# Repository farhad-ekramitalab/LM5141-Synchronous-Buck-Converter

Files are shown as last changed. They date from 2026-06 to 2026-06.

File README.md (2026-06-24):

# LM5141-Q1 Synchronous Buck Converter

## Project Overview

Design and implementation of a 12 V to 3.3 V, 5 A synchronous buck converter using the Texas Instruments LM5141-Q1 peak-current-mode controller.

This project covers the complete development flow:

- Power-stage design
- LTspice simulation
- Control-loop design
- Compensation design
- KiCad schematic capture
- 4-layer PCB layout
- Manufacturing preparation
- Hardware validation (in progress)
Schematic KiCad
Layout KiCad
3D Render KiCad

---
## 📄 Portfolio Report

A concise engineering portfolio summarizing the complete design workflow, including system specifications, LTspice simulations, control-loop design, PCB implementation, manufacturing, and engineering skills demonstrated throughout the project.

**Report:**

[`Docs/LM5141-Synchronous Buck Converter Report.pdf`](Docs/LM5141-Synchronous%20Buck%20Converter%20Report.pdf)

## Specifications

| Parameter | Value |
|---|---|
| Input Voltage | 8 V – 16 V |
| Nominal Input Voltage | 12 V |
| Output Voltage | 3.3 V |
| Output Current | 5 A |
| Switching Frequency | 440 kHz |
| Topology | Synchronous Buck |
| Controller | LM5141-Q1 |
| Control Method | Peak Current Mode |

---

## Design Highlights

- Peak current mode control
- Type-II compensation network
- Loop crossover frequency ≈ 37 kHz
- Phase margin ≈ 83°
- 4-layer PCB implementation
- Kelvin current sensing
- AGND / PGND separation
- Optimized switching-node layout

---

## Current Status

- [x] Power stage design completed
- [x] LTspice simulation completed
- [x] Compensation design completed
- [x] KiCad schematic completed
- [x] PCB layout completed
- [x] PCB ordered
- [ ] Assembly
- [ ] Hardware validation
- [ ] Efficiency characterization
- [ ] Thermal characterization
---

## Tools Used

- LTspice
- KiCad 9
- TI WEBENCH
- Oscilloscope (planned validation)

---

## 🔗 Additional Resources

* 📁 **KiCad Project:** `KiCad/`
* ⚡ **LTspice Simulations:** `LTspice/`
* 🖼️ **Project Images:** `Images/`
* 📦 **Bill of Materials (BOM):** `BOM/`
* 📄 **Portfolio Report:** `Docs/LM5141-Synchronous Buck Converter Report.pdf`

---

## Author

Farhad Ekramitalab

Hardware Engineer | Power Electronics | SMPS | PCB Design | LTspice

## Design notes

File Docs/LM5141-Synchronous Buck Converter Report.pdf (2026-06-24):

LM5141-Q1 Automotive Synchronous Buck Converter

### 12 V → 3.3 V, 5 A | Peak Current Mode Control

Farhad Ekramitalab
Hardware Engineer | Power Electronics | PCB Design | LTspice | KiCad

PROJECT OVERVIEW

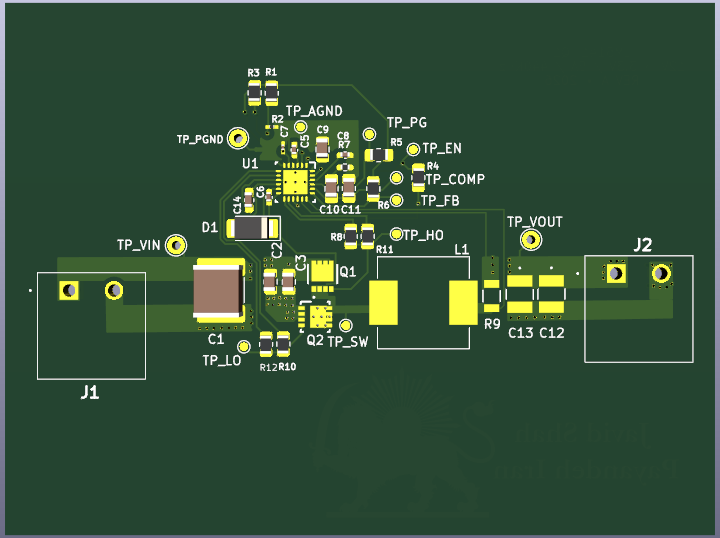
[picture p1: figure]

Project Summary
This project presents the complete design and implementation of a 12 V to 3.3 V, 5 A synchronous buck converter using the Texas Instruments LM5141-Q1 automotive-qualified controller.
The project was developed following a complete engineering workflow including system specification, power-stage design, control-loop design, LTspice simulation, schematic capture, PCB layout, and manufacturing preparation.
The design was implemented using LTspice, TI WEBENCH, and KiCad and has been released for PCB fabrication through JLCPCB.

Key Specifications

Parameter | Value
Input Voltage | 8 V – 16 V
Nominal Input | 12 V
Output Voltage | 3.3 V
Output Current | 5 A

Switching Frequency 440 kHz

Topology | Synchronous Buck
Controller | LM5141-Q1
Control Method | Peak Current Mode
PCB Stackup | 4 Layers

Industry Relevance
The converter was developed following automotive and industrial power electronics design practices.
Particular attention was given to EMC-aware PCB layout techniques including:
- Hot-loop minimization
- Compact switching-node geometry
- Kelvin current sensing
- AGND / PGND separation
- Optimized gate-drive routing
These design practices are commonly used in professional automotive power conversion systems and support future EMC/EMI compliance activities.

CONTROL LOOP DESIGN & SIMULATION

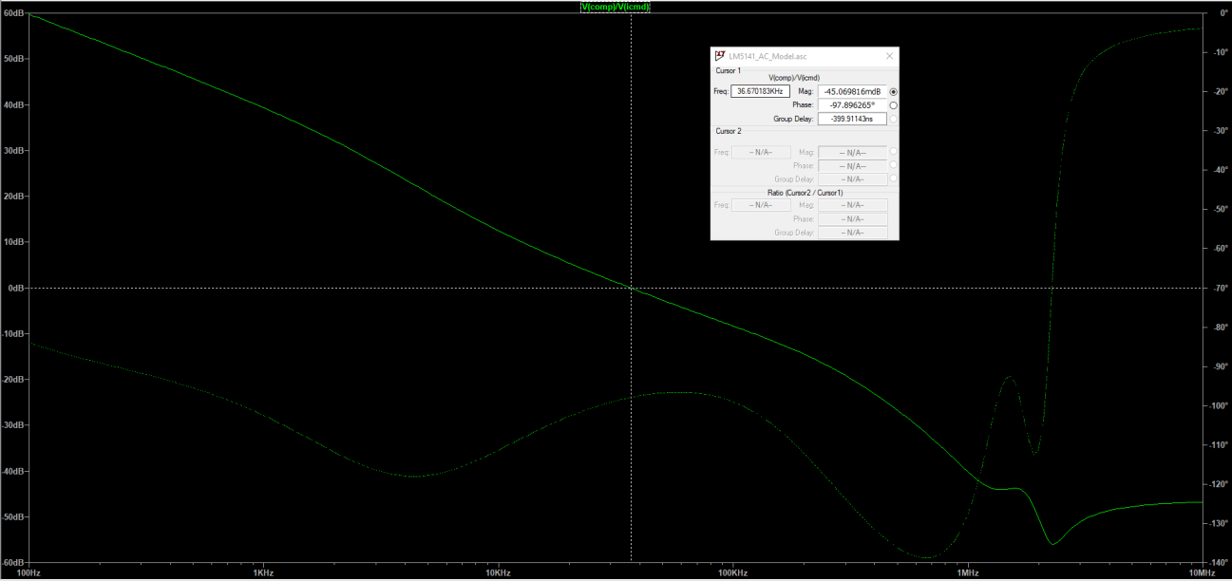
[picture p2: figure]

Stability Results
- Control Method: Peak Current Mode
- Compensation: Type-II
- Crossover Frequency: ~37 kHz
- Phase Margin: ~83°
- Switching Frequency: 440 kHz
The compensation network was designed and validated using LTspice averaged AC analysis. The resulting loop response provides robust stability and excellent transient performance while maintaining sufficient bandwidth for fast load regulation. Simulation Activities
- Startup analysis
- Load transient analysis
- Line transient analysis
- Loop-gain verification
- Compensation optimization

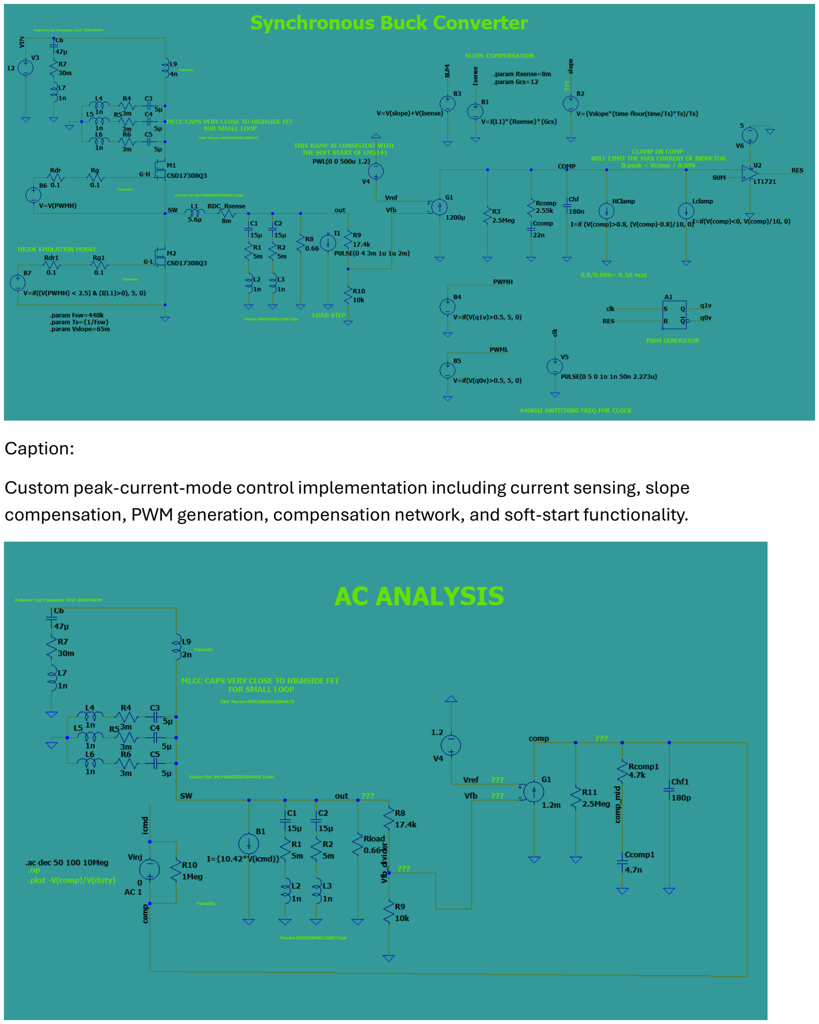
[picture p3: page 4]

Caption:
Custom peak-current-mode control implementation including current sensing, slope compensation, PWM generation, compensation network, and soft-start functionality.

SCHEMATIC & PCB IMPLEMENTATION Schematic Capture

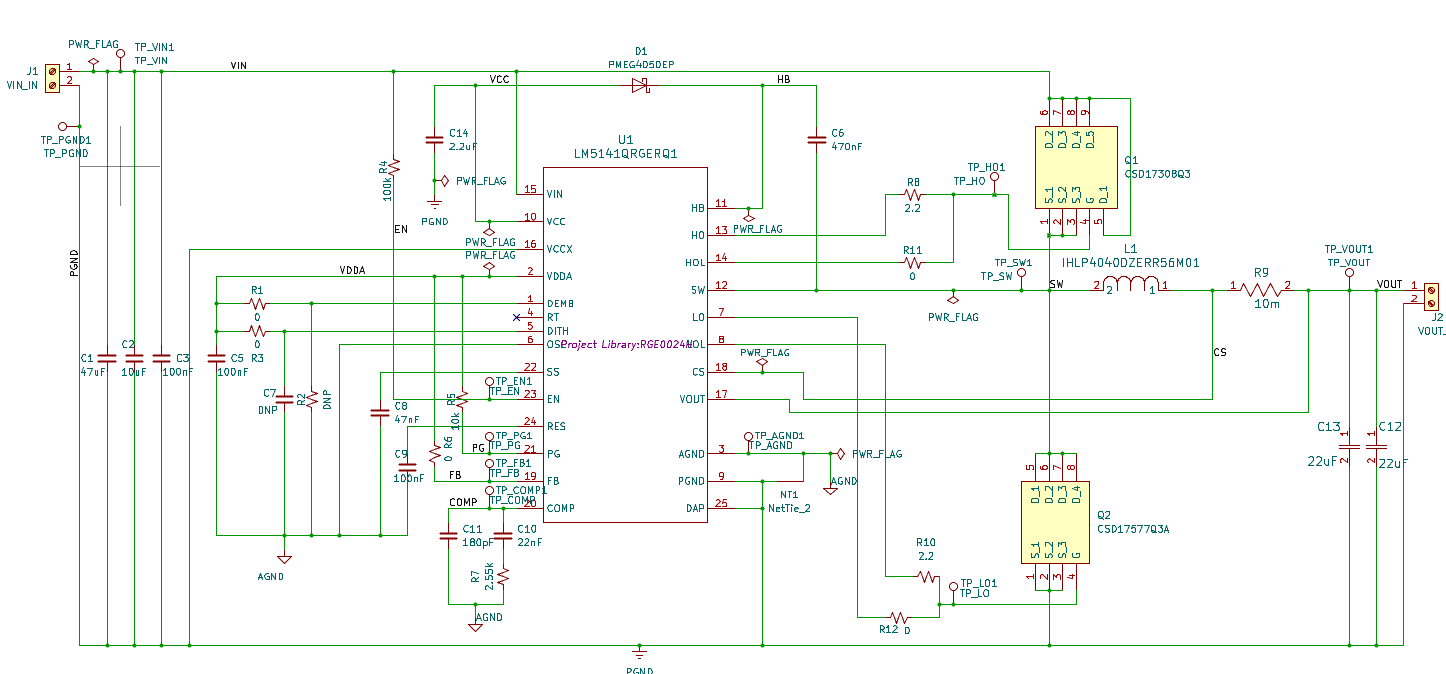
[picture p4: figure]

The complete converter was implemented in KiCad and includes:
- LM5141-Q1 controller
- Bootstrap circuitry
- Synchronous MOSFET stage
- Current sensing network
- Compensation network
- Input and output filtering

PCB Layout

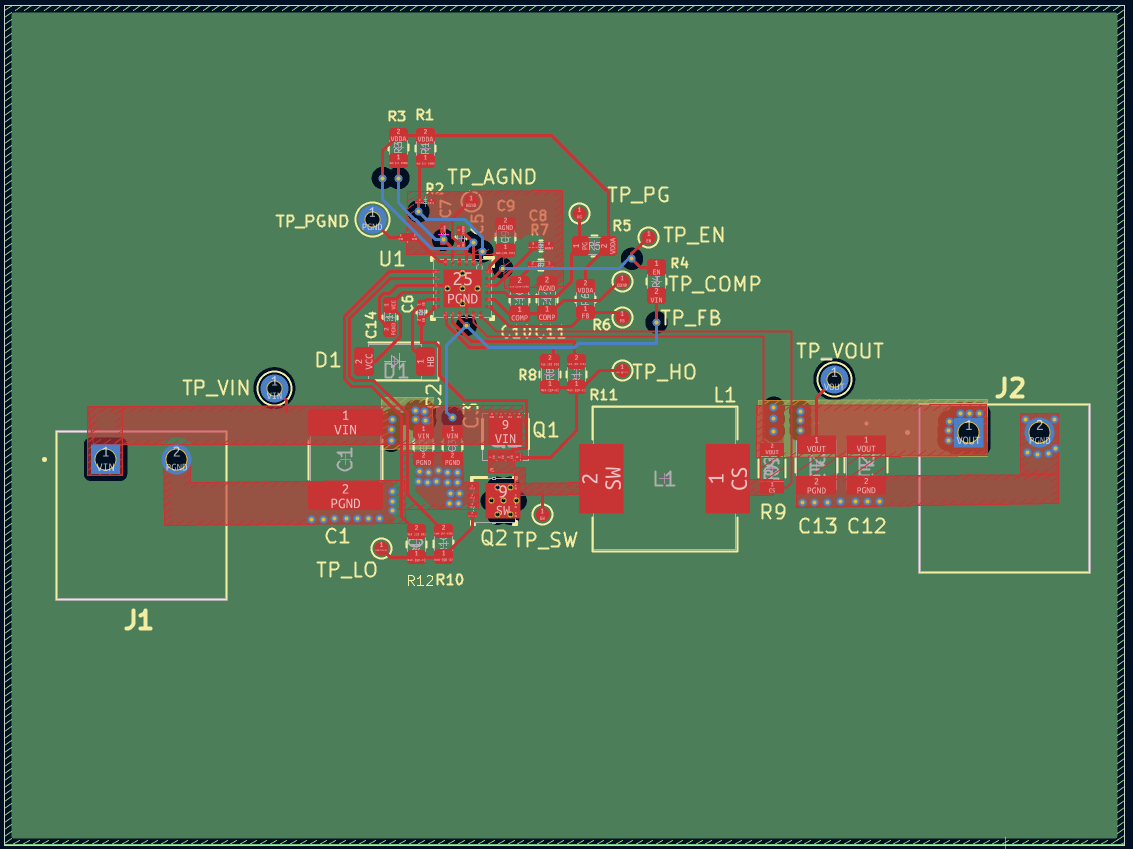
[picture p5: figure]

The PCB was implemented as a four-layer design using industry-standard switching power supply layout techniques.
Layout Highlights
- Hot-loop minimization
- Compact power-stage placement
- Kelvin current sensing
- AGND / PGND separation using net tie
- Short gate-drive loops
- Test-point strategy for validation
- Manufacturing-ready layout

Engineering Skills Demonstrated:

Power Electronics Design - DC-DC Converter Design - Peak Current Mode Control -Compensation Design - Loop Stability Analysis - LTspice Simulation - PCB Design (KiCad) -EMC-Aware Layout Techniques - Design for Manufacturing (DFM) - Technical Documentation

Engineering Tools:
✓ LTspice
✓ KiCad
✓ TI WEBENCH
✓ JLCPCB
✓ Datasheet Analysis
✓ PCB Design
Repository
GitHub Repository:
https://github.com/farhad-ekramitalab/LM5141-Synchronous-Buck-Converter
Future Validation Plan
The next phase of the project includes hardware assembly and laboratory characterization. Planned validation activities include:
- Startup verification
- Output ripple measurement
- Load transient testing
- Efficiency characterization
- Thermal analysis
- EMI/EMC-oriented waveform evaluation
This project demonstrates the complete workflow of a modern power electronics design from specification through simulation, PCB implementation, and manufacturing release.

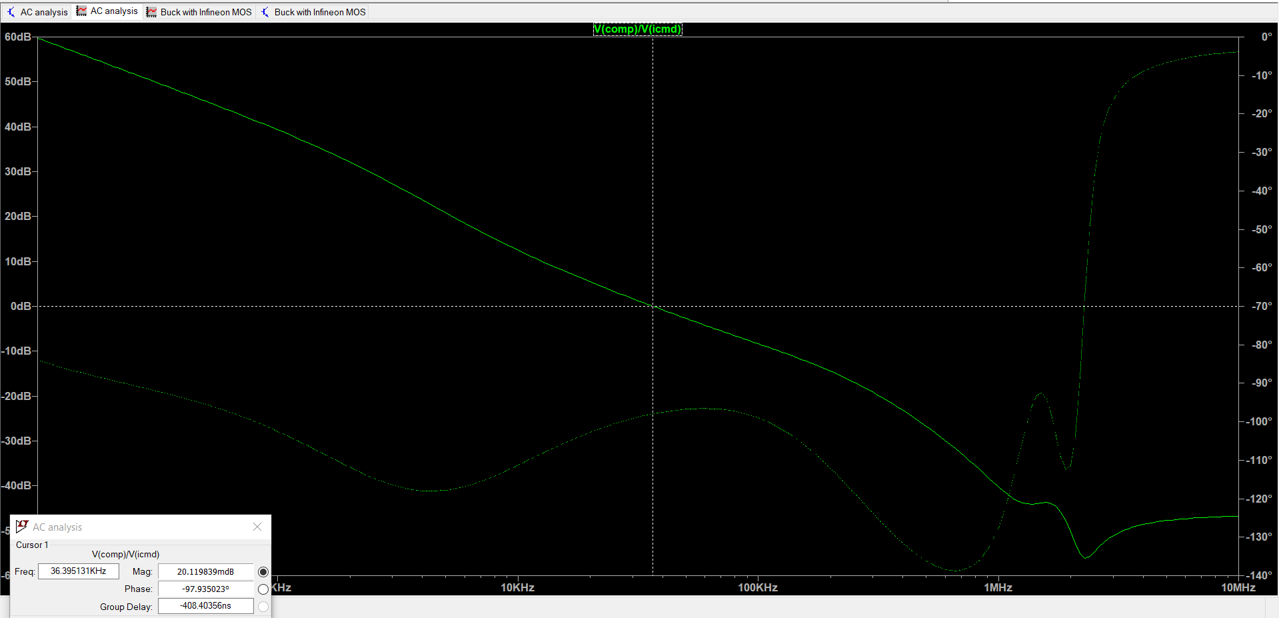
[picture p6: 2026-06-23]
Images/Bode Plot.PNG

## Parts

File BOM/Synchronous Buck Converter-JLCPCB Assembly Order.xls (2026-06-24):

JLCPCB BOM Tool - BOM Matching
BOM name：Synchronous Buck Converter-JLCPCB Assembly Order.xlsx |  |  | Download Time：2026-06-23 06:31:29 |  |  |  | * Our matching results are updated in real-time, but stock and prices may change. If it's been over 24 hours, please re-match before placing your order.
PCB Assembled Qty：5 |  |  | Est. Total Price：35.0266
Your BOM |  |  |  |  | Matched Parts |  |  |  |  |  |  | Order Information
Top Designator | Bottom Designator | Comment | Footprint | JLCPCB Part # | Matches | Part # | Manufacturer | Footprint | Description | Category | Warning | JLCPCB Part # | Product link | Lib Type | Qty | Source | Total Price ($)
C1 |  | 47uF | Capacitor_SMD:C_2220_5750Metric_Pad1.97x5.40mm_HandSolder |  | Select by Customer | FS55X476K250LRG | PSA(Prosperity Dielectrics) | 2220 | 25V 47uF X7R ±10% 2220 Multilayer Ceramic Capacitors MLCC - SMD/SMT ROHS | Multilayer Ceramic Capacitors MLCC - SMD/SMT |  | C22388555 | https://jlcpcb.com/partdetail/23956927-FS55X476K250LRG/C22388555 | Extended | 5 | 5 JLCPCB | 5.5005
C2 |  | 10uF | Capacitor_SMD:C_0805_2012Metric |  | Select by System | GRM21BR61H106KE43L | Murata Electronics | 0805 | 10uF 50V X5R ±10% 0805 Multilayer Ceramic Capacitors MLCC - SMD/SMT ROHS | Multilayer Ceramic Capacitors MLCC - SMD/SMT |  | C440198 | https://jlcpcb.com/partdetail/439567-GRM21BR61H106KE43L/C440198 | Basic | 5 | 5 JLCPCB | 0.456
C3,C9 |  | 100nF | Capacitor_SMD:C_0805_2012Metric |  | Select by System | CC0805KRX7R9BB104 | YAGEO | 0805 | 100nF 50V X7R ±10% 0805 Multilayer Ceramic Capacitors MLCC - SMD/SMT ROHS | Multilayer Ceramic Capacitors MLCC - SMD/SMT |  | C49678 | https://jlcpcb.com/partdetail/YAGEO-CC0805KRX7R9BB104/C49678 | Basic | 10 | 10 JLCPCB | 0.115
C5 |  | 100nF | Capacitor_SMD:C_0402_1005Metric_Pad0.74x0.62mm_HandSolder |  | Select by Customer | CC0402KRX7R8BB104 | YAGEO | 0402 | 100nF 25V X7R ±10% 0402 Multilayer Ceramic Capacitors MLCC - SMD/SMT ROHS | Multilayer Ceramic Capacitors MLCC - SMD/SMT |  | C105883 | https://jlcpcb.com/partdetail/YAGEO-CC0402KRX7R8BB104/C105883 | Extended | 20 | 20 JLCPCB | 0.174
C6 |  | 470nF | Capacitor_SMD:C_0402_1005Metric_Pad0.74x0.62mm_HandSolder |  | Select by Customer | CGA0402X7R474K160GT | HRE | 0402 | 16V 470nF X7R ±10% 0402 Multilayer Ceramic Capacitors MLCC - SMD/SMT ROHS | Multilayer Ceramic Capacitors MLCC - SMD/SMT |  | C22435970 | https://jlcpcb.com/partdetail/HRE-CGA0402X7R474K160GT/C22435970 | Extended | 20 | 20 JLCPCB | 0.306
C8 |  | 47nF | Capacitor_SMD:C_0402_1005Metric_Pad0.74x0.62mm_HandSolder |  | Select by Customer | 0402B473K500NT | FH (Guangdong Fenghua Advanced Tech) | 0402 | 47nF 50V X7R ±10% 0402 Multilayer Ceramic Capacitors MLCC - SMD/SMT ROHS | Multilayer Ceramic Capacitors MLCC - SMD/SMT |  | C82219 | https://jlcpcb.com/partdetail/83376-0402B473K500NT/C82219 | Extended | 20 | 20 JLCPCB | 0.068
C10 |  | 22nF | Capacitor_SMD:C_0805_2012Metric_Pad1.18x1.45mm_HandSolder |  | Select by System | CL21B223KBANNNC | Samsung Electro-Mechanics | 0805 | 22nF 50V X7R ±10% 0805 Multilayer Ceramic Capacitors MLCC - SMD/SMT ROHS | Multilayer Ceramic Capacitors MLCC - SMD/SMT |  | C1729 | https://jlcpcb.com/partdetail/2081-CL21B223KBANNNC/C1729 | Basic | 5 | 5 JLCPCB | 0.063
C11 |  | 180pF | Capacitor_SMD:C_0805_2012Metric_Pad1.18x1.45mm_HandSolder |  | Select by System | CC0805FRNPO9BN181 | YAGEO | 0805 | 180pF 50V NP0 ±1% 0805 Multilayer Ceramic Capacitors MLCC - SMD/SMT ROHS | Multilayer Ceramic Capacitors MLCC - SMD/SMT |  | C527080 | https://jlcpcb.com/partdetail/YAGEO-CC0805FRNPO9BN181/C527080 | Extended | 20 | 20 JLCPCB | 0.742
C12,C13 |  | 22uF | MSASE32MSB7226MPNB25:CAP_MSAS_32MS_TAY |  | Select by Customer | MCAST32MSB7226KPNA01 | Taiyo Yuden | 1210 | 22uF 25V X7R ±10% 1210 Multilayer Ceramic Capacitors MLCC - SMD/SMT ROHS | Multilayer Ceramic Capacitors MLCC - SMD/SMT |  | C5372271 | https://jlcpcb.com/partdetail/TaiyoYuden-MCAST32MSB7226KPNA01/C5372271 | Extended | 10 | 10 JLCPCB | 1.959
C14 |  | 2.2uF | Capacitor_SMD:C_0603_1608Metric_Pad1.08x0.95mm_HandSolder |  | Select by System | CL10A225KO8NNNC | Samsung Electro-Mechanics | 0603 | 16V 2.2uF X5R ±10% 0603 Multilayer Ceramic Capacitors MLCC - SMD/SMT ROHS | Multilayer Ceramic Capacitors MLCC - SMD/SMT |  | C23630 | https://jlcpcb.com/partdetail/24366-CL10A225KO8NNNC/C23630 | Basic | 5 | 5 JLCPCB | 0.046
D1 |  | PMEG4050EP | Diode_SMD:D_SOD-128 |  | Select by Customer | PMEG4050EP-FS | FUXINSEMI | SOD-128 | 1 Independent 120A 300uA 40V 450mV@5A 5A SOD-128 Schottky Diodes ROHS |  | 1.The comment (PMEG4050EP-FS) of this part does not match the one (PMEG4050EP) provided in your BOM. Please confirm; | C42387310 | https://jlcpcb.com/partdetail/FUXINSEMI-PMEG4050EPFS/C42387310 | Extended | 7 | 7 JLCPCB | 0.8176
L1 |  | IHLP4040DZERR56M01 | Inductor_SMD:L_Vishay_IHLP-4040 |  | Select by System | IHLP4040DZERR56M01 | Vishay Intertech | SMD,10.8x10.2mm | 1.95mΩ 27.5A 49A 560nH ±20% SMD,10.8x10.2mm Inductors (SMD) ROHS | Inductors (SMD) |  | C845086 | https://jlcpcb.com/partdetail/VishayIntertech-IHLP4040DZERR56M01/C845086 | Extended | 5 | 5 JLCPCB | 5.911
Q1 |  | CSD17308Q3 | CSD17308Q3:CSD17308Q3 |  | Select by System | CSD17308Q3 | Texas Instruments | VSON-CLIP-8(3.3x3.3) | -55℃~+150℃ 1 N-channel 1.8V 12.5mΩ@3V 28W 3.9nC@4.5V 30V 35pF 365pF 50A 700pF N-Channel VSON-CLIP-8(3.3x3.3) MOSFETs ROHS | MOSFETs |  | C294987 | https://jlcpcb.com/partdetail/TexasInstruments-CSD17308Q3/C294987 | Extended | 5 | 5 JLCPCB | 3.511
Q2 |  | CSD17577Q3A | CSD17577Q3A:DNH0008A |  | Select by System | CSD17577Q3A | Texas Instruments | VSONP-8(3.3x3.3) | -55℃~+150℃ 1 N-channel 1.8V 103pF 2.31nF 270pF 30V 35nC@10V 53W 6.4mΩ@4.5V 83A N-Channel VSONP-8(3.3x3.3) MOSFETs ROHS | MOSFETs |  | C201632 | https://jlcpcb.com/partdetail/TexasInstruments-CSD17577Q3A/C201632 | Extended | 5 | 5 JLCPCB | 2.537
R1,R3,R6,R11,R12 |  | 0 | Resistor_SMD:R_0805_2012Metric |  | Select by Customer | 0805W8F0000T5E | UNI-ROYAL(Uniroyal Elec) | 0805 | -55℃~+155℃ 0Ω 125mW 150V Thick Film Resistor ±1% ±800ppm/℃ 0805 Chip Resistor - Surface Mount ROHS | Chip Resistor - Surface Mount | 1.The comment (0805W8F0000T5E) of this part does not match the one (0) provided in your BOM. Please confirm; | C17477 | https://jlcpcb.com/partdetail/18165-0805W8F0000T5E/C17477 | Basic | 25 | 25 JLCPCB | 0.075
R4 |  | 100k | Resistor_SMD:R_0805_2012Metric_Pad1.20x1.40mm_HandSolder |  | Select by Customer | 0805W8F1003T5E | UNI-ROYAL(Uniroyal Elec) | 0805 | -55℃~+155℃ 100kΩ 125mW 150V Thick Film Resistor ±1% ±100ppm/℃ 0805 Chip Resistor - Surface Mount ROHS | Chip Resistor - Surface Mount | 1.The comment (0805W8F1003T5E) of this part does not match the one (100k) provided in your BOM. Please confirm; | C149504 | https://jlcpcb.com/partdetail/160838-0805W8F1003T5E/C149504 | Basic | 5 | 5 JLCPCB | 0.016
R5 |  | 10k | Resistor_SMD:R_0805_2012Metric_Pad1.20x1.40mm_HandSolder |  | Select by Customer | 0805W8F1002T5E | UNI-ROYAL(Uniroyal Elec) | 0805 | -55℃~+155℃ 10kΩ 125mW 150V Thick Film Resistor ±1% ±100ppm/℃ 0805 Chip Resistor - Surface Mount ROHS | Chip Resistor - Surface Mount | 1.The comment (0805W8F1002T5E) of this part does not match the one (10k) provided in your BOM. Please confirm; | C17414 | https://jlcpcb.com/partdetail/18102-0805W8F1002T5E/C17414 | Basic | 5 | 5 JLCPCB | 0.017
R7 |  | 2.55k | Resistor_SMD:R_0402_1005Metric_Pad0.72x0.64mm_HandSolder |  | Select by Customer | CR0402FF2551G | LIZ Elec | 0402 | -55℃~+125℃ 2.55kΩ 50V 62.5mW Thick Film Resistor ±1% ±200ppm/℃ 0402 Chip Resistor - Surface Mount ROHS | Chip Resistor - Surface Mount | 1.The comment (CR0402FF2551G) of this part does not match the one (2.55k) provided in your BOM. Please confirm; | C100338 | https://jlcpcb.com/partdetail/LIZElec-CR0402FF2551G/C100338 | Extended | 20 | 20 JLCPCB | 0.012
R8,R10 |  | 2.2 | Resistor_SMD:R_0805_2012Metric |  | Select by Customer | 0603WAF220KT5E | UNI-ROYAL(Uniroyal Elec) | 0603 | -55℃~+155℃ 100mW 2.2Ω 75V Thick Film Resistor ±1% ±400ppm/℃ 0603 Chip Resistor - Surface Mount ROHS | Chip Resistor - Surface Mount | 1.The comment (0603WAF220KT5E) of this part does not match the one (2.2) provided in your BOM. Please confirm; | C22939 | https://jlcpcb.com/partdetail/23666-0603WAF220KT5E/C22939 | Basic | 10 | 10 JLCPCB | 0.023
R9 |  | 10m | CSR1206FK10L0:STA_CSR1206_STP |  | Select by Customer | FMF06FTHR010-LH | PSA(Prosperity Dielectrics) | 1206 | 10mΩ 1W Current Sense Resistor SMD ±1% ±70ppm/℃ 1206 Current Sense Resistors / Shunt Resistors ROHS | Current Sense Resistors / Shunt Resistors | 1.The comment (FMF06FTHR010-LH) of this part does not match the one (10m) provided in your BOM. Please confirm; | C105362 | https://jlcpcb.com/partdetail/106577-FMF06FTHR010LH/C105362 | Extended | 15 | 15 JLCPCB | 0.6465
U1 |  | LM5141QRGERQ1 | ProjectLibrary:RGE0024H |  | Select by Customer | LM5141QRGERQ1 | Texas Instruments | VQFN-24-EP(4x4) | -40℃~+150℃@(TJ) 1 1.5V~15V 3.8V~65V 35uA 440kHz、2.2MHz Adjustable Buck Buck External Yes VQFN-24-EP(4x4) DC-DC Converters ROHS | DC-DC Converters |  | C2658684 | https://jlcpcb.com/partdetail/TexasInstruments-LM5141QRGERQ1/C2658684 | Extended | 5 | 5 JLCPCB | 12.031
C7 |  | DNP | Capacitor_SMD:C_0201_0603Metric_Pad0.64x0.40mm_HandSolder |  | No matches | No Part Selected
R2 |  | DNP | Resistor_SMD:R_0201_0603Metric_Pad0.64x0.40mm_HandSolder |  | No matches | No Part Selected

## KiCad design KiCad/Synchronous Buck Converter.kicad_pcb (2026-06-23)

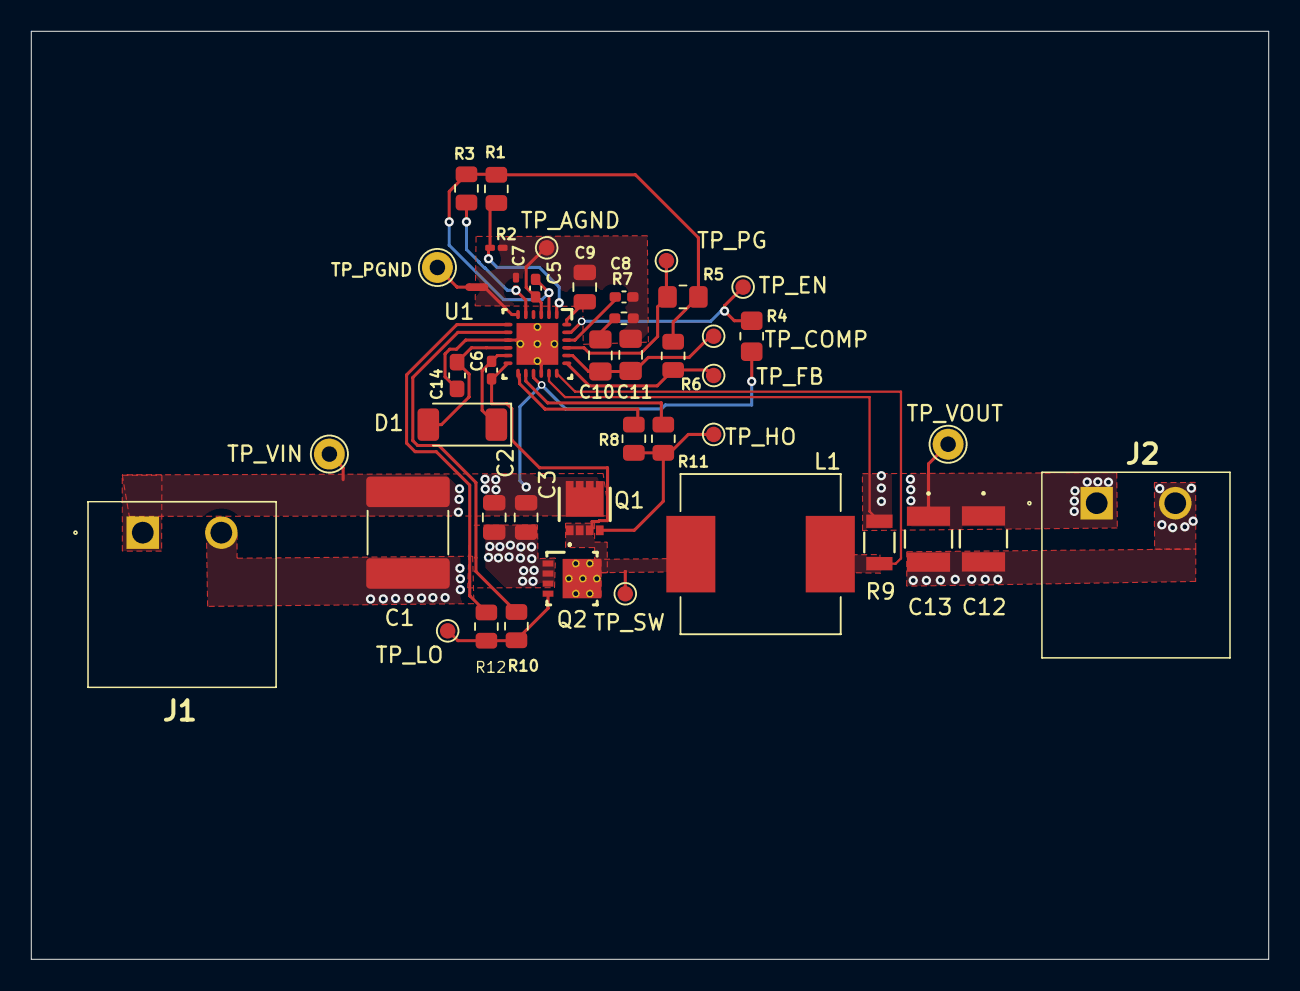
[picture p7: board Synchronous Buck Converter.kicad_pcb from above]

Board: 4 copper layers, 80.0 x 60.0 mm, 44 parts (0 on the bottom side), 24 nets.

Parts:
C1: 47uF; C_2220_5750Metric_Pad1.97x5.40mm_HandSolder
C2: 10uF; C_0805_2012Metric
C3, C9: 100nF; C_0805_2012Metric
C5: 100nF; C_0402_1005Metric_Pad0.74x0.62mm_HandSolder
C6: 470nF; C_0402_1005Metric_Pad0.74x0.62mm_HandSolder
C7: DNP; C_0201_0603Metric_Pad0.64x0.40mm_HandSolder
C8: 47nF; C_0402_1005Metric_Pad0.74x0.62mm_HandSolder
C10: 22nF; C_0805_2012Metric_Pad1.18x1.45mm_HandSolder
C11: 180pF; C_0805_2012Metric_Pad1.18x1.45mm_HandSolder
C12, C13: 22uF; CAP_MSAS_32MS_TAY
C14: 2.2uF; C_0603_1608Metric_Pad1.08x0.95mm_HandSolder
D1: PMEG4050EP; D_SOD-128
J1: VIN_IN; 1757242
J2: VOUT_OUT; 1757242
L1: IHLP4040DZERR56M01; L_Vishay_IHLP-4040
NT1: NetTie_2; NetTie-2_SMD_Pad0.5mm
Q1: CSD17308Q3
Q2: CSD17577Q3A; DNH0008A
R1, R3, R6, R11, R12: 0; R_0805_2012Metric
R2: DNP; R_0201_0603Metric_Pad0.64x0.40mm_HandSolder
R4: 100k; R_0805_2012Metric_Pad1.20x1.40mm_HandSolder
R5: 10k; R_0805_2012Metric_Pad1.20x1.40mm_HandSolder
R7: 2.55k; R_0402_1005Metric_Pad0.72x0.64mm_HandSolder
R8, R10: 2.2; R_0805_2012Metric
R9: 10m; STA_CSR1206_STP
TP_AGND: TP_AGND; TestPoint_Pad_D1.0mm
TP_COMP: TP_COMP; TestPoint_Pad_D1.0mm
TP_EN: TP_EN; TestPoint_Pad_D1.0mm
TP_FB: TP_FB; TestPoint_Pad_D1.0mm
TP_HO: TP_HO; TestPoint_Pad_D1.0mm
TP_LO: TP_LO; TestPoint_Pad_D1.0mm
TP_PG: TP_PG; TestPoint_Pad_D1.0mm
TP_PGND: TP_PGND; TestPoint_THTPad_D2.0mm_Drill1.0mm
TP_SW: TP_SW; TestPoint_Pad_D1.0mm
TP_VIN: TP_VIN; TestPoint_THTPad_D2.0mm_Drill1.0mm
TP_VOUT: TP_VOUT; TestPoint_THTPad_D2.0mm_Drill1.0mm
U1: LM5141QRGERQ1; RGE0024H

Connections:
/COMP: C10.1, C11.1, TP_COMP.1, U1.20 (COMP)
/CS: L1.1, R9.1, U1.18 (CS)
/EN: R4.1, TP_EN.1, U1.23 (EN)
/FB: R6.1, TP_FB.1, U1.19 (FB)
/HB: C6.1, D1.1 (K), U1.11 (HB)
/PG: R5.1, TP_PG.1, U1.21 (PG)
/SW: C6.2, L1.2, Q1.1 (S_1), Q1.2 (S_2), Q1.3 (S_3), Q2.5 (D_1), Q2.6 (D_2), Q2.7 (D_3), Q2.8 (D_4), Q2.9, TP_SW.1, U1.12 (SW)
/VCC: C14.1, D1.2 (A), U1.10 (VCC)
/VDDA: C5.1, R1.2, R3.2, R5.2, R6.2, U1.2 (VDDA)
/VIN: C1.1, C2.1, C3.1, J1.1 (VIN), Q1.5 (D_1), Q1.6 (D_2), Q1.7 (D_3), Q1.8 (D_4), Q1.9 (D_5), R4.2, TP_VIN.1, U1.15 (VIN)
/VOUT: C12.1, C13.1, J2.1 (VIN), R9.2, TP_VOUT.1, U1.17 (VOUT)
AGND: C5.2, C7.2, C8.2, C9.2, C11.2, NT1.2, R2.1, R7.1, TP_AGND.1, U1.3 (AGND), U1.6 (OSC)
unnamed: C10.2, R7.2
unnamed: Q1.4 (G), R8.1, R11.1, TP_HO.1
unnamed: Q2.4 (G), R10.1, R12.1, TP_LO.1
unnamed: R1.1, R2.2, U1.1 (DEMB)
unnamed: C7.1, R3.1, U1.5 (DITH)
unnamed: R8.2, U1.13 (HO)
unnamed: R11.2, U1.14 (HOL)
unnamed: R12.2, U1.7 (LO)
unnamed: R10.2, U1.8 (LOL)
unnamed: C9.1, U1.24 (RES)
unnamed: C8.1, U1.22 (SS)
PGND: C1.2, C2.2, C3.2, C12.2, C13.2, C14.2, J1.2 (PGND), J2.2 (PGND), NT1.1, Q2.1 (S_1), Q2.2 (S_2), Q2.3 (S_3), TP_PGND.1, U1.9 (PGND), U1.16 (VCCX), U1.25 (DAP)
